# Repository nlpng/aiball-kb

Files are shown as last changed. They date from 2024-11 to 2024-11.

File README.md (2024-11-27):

# aiball keyboard
A 42-key splited keyboard inspired by [keyball](https://github.com/Yowkees/keyball) and [roBa](https://github.com/kumamuk-git/roBa), which has feature of trackball and wireless.

# Changes
The keyboard is based on roBa keyboard, and rework to fit my personal needs, since Corne keyboard layout is preferred, the key access feels better and more compact to me.

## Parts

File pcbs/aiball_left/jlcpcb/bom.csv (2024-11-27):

Designator | Footprint | Quantity | Value | LCSC Part #
B1 | JST_S2B-PH-SM4-TB | 1 | BATT
D1, D10, D11, D12, D13, D14, D15, D16, D17, D18, D19, D2, D20, D21, D22, D23, D3, D4, D5, D6, D7, D8, D9 | Diode_SMD | 23 | D
J1, J2, J3, J4, J5, J6, J7 | MountingHole_4.3mm_M4 | 7 | Conn_01x01-Connector_Generic
SW1, SW10, SW11, SW12, SW13, SW14, SW15, SW17, SW18, SW19, SW2, SW22, SW3, SW4, SW5, SW6, SW7, SW8, SW9 | SW_MX | 19 | SW_PUSH
SW16, SW20, SW23 | SW_MX_Choc | 3 | SW_PUSH
SW21 | SW_MX_EC12 | 1 | RotaryEncoder_Switch
SW24 | TGSW_MSK-12D19 | 1 | SW_SPDT
U1 | XIAO_nRF52840_wBAT_wNFC_1 | 1 | ~

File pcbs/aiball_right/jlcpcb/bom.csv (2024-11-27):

Designator | Footprint | Quantity | Value | LCSC Part #
BT1 | JST_S2B-PH-SM4-TB | 1 | BATT
D1, D10, D11, D12, D13, D14, D15, D16, D17, D18, D19, D2, D20, D3, D4, D5, D6, D7, D8, D9 | Diode_SMD | 20 | D
J1 | pmw3610_connector | 1 | ~
J2, J3, J4, J5, J6, J7 | MountingHole_4.3mm_M4 | 6 | Conn_01x01-Connector_Generic
SW1, SW10, SW11, SW13, SW14, SW15, SW17, SW18, SW19, SW2, SW20, SW3, SW4, SW5, SW6, SW7, SW8, SW9 | SW_MX | 18 | SW_PUSH
SW12, SW16 | SW_MX_Choc | 2 | SW_PUSH
SW21 | TGSW_MSK-12D19 | 1 | SW_SPDT
U1 | XIAO_nRF52840_wBAT_wNFC_1 | 1 | ~

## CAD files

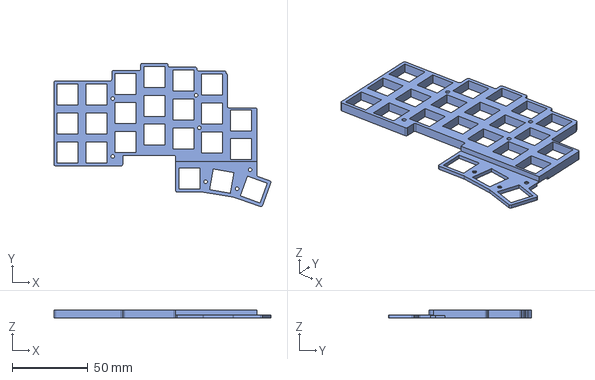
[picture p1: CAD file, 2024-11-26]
cases/step/left_top_plate.step
142.9 x 94.5 x 5.00 mm

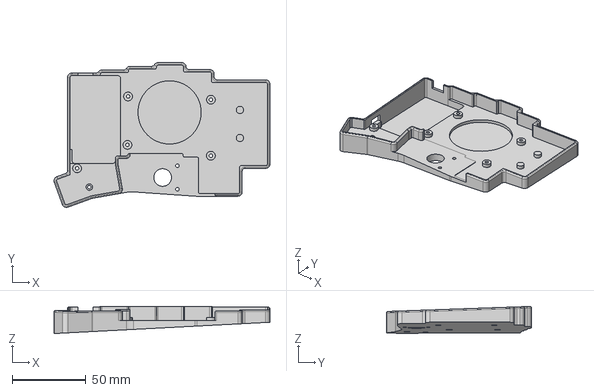
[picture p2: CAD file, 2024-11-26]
cases/step/right_bottom_plate.step
146.9 x 98.5 x 18.4 mm

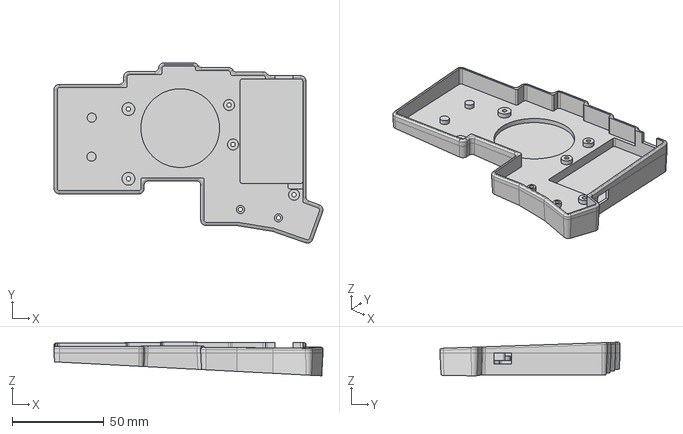
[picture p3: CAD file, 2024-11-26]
cases/step/left_bottom_plate.step
146.9 x 98.5 x 18.4 mm

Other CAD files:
cases/step/right_top_plate.step
cases/stl/left_bottom_plate.stl
cases/stl/left_top_plate.stl
cases/stl/right_top_plate.stl

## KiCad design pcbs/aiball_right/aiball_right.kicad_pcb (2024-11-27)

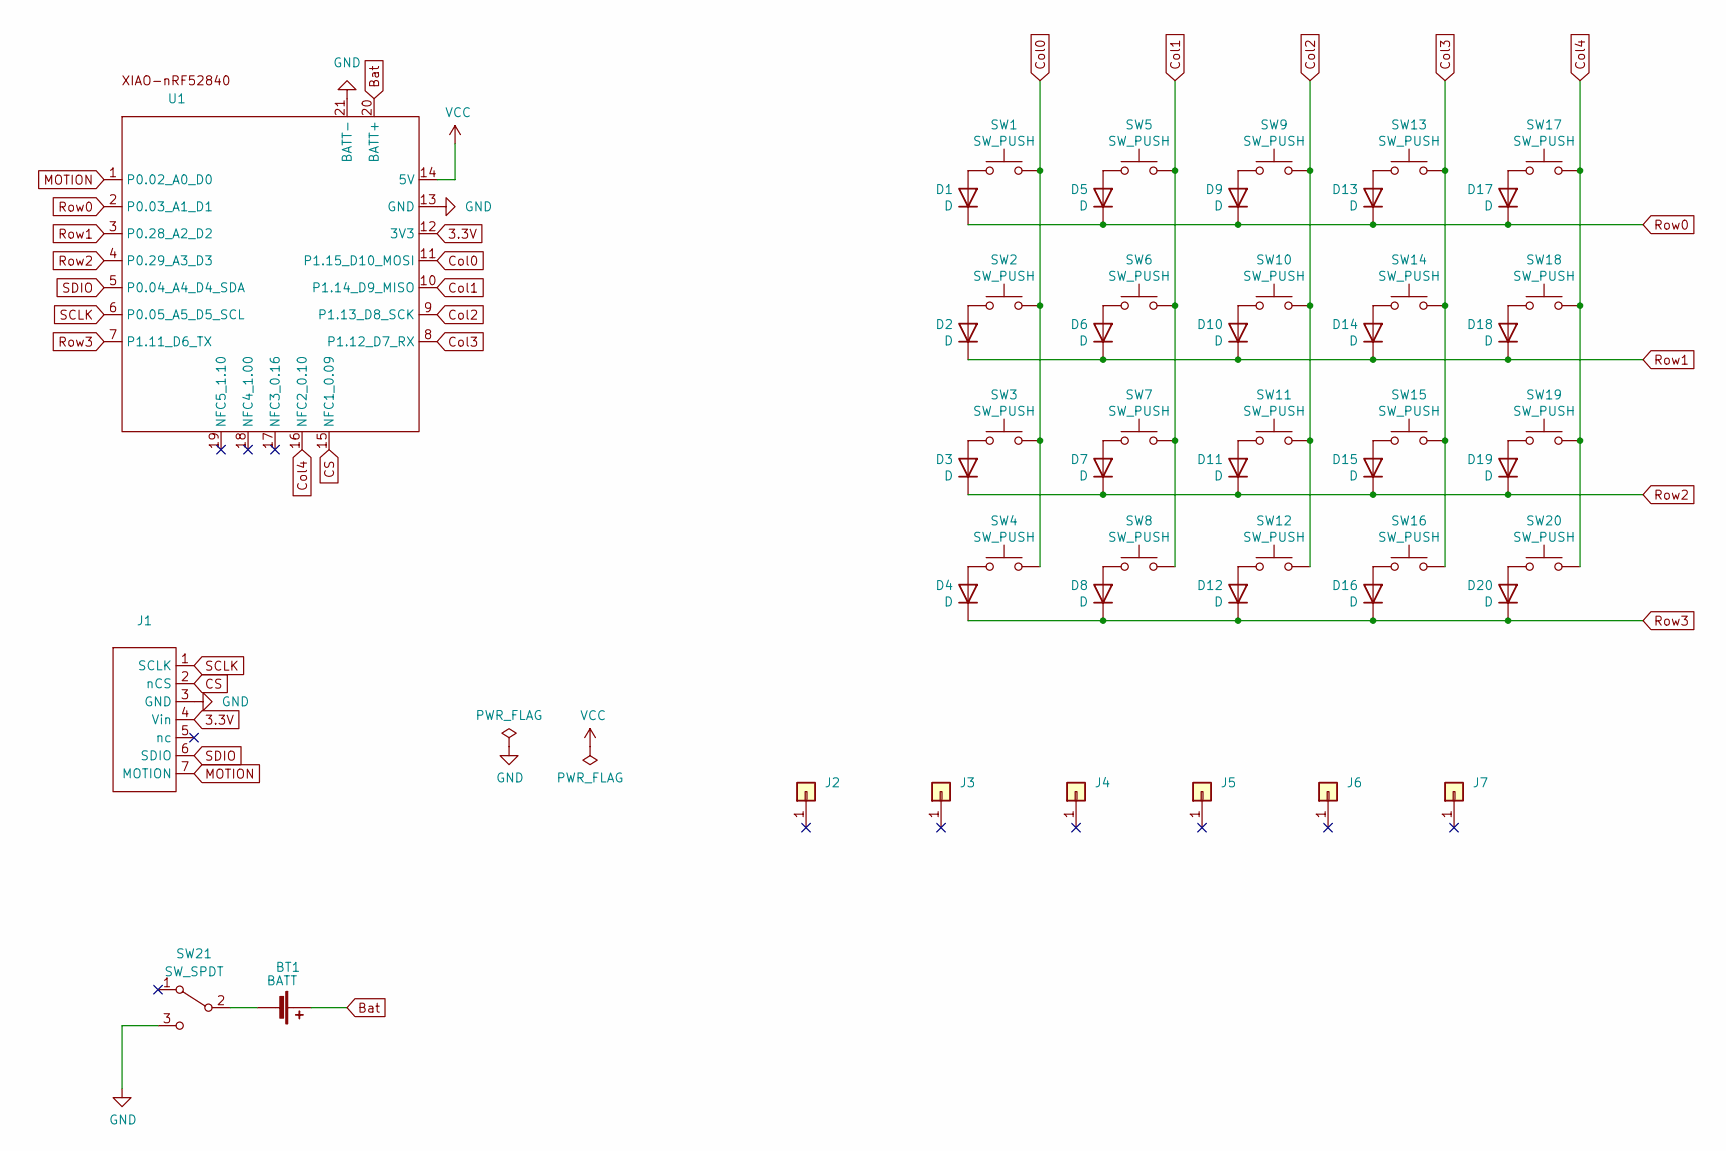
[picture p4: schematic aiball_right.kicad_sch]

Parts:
BT1: BATT; JST_S2B-PH-SM4-TB
D1, D2, D3, D4, D5, D6, D7, D8, D9, D10, D11, D12, D13, D14, D15, D16, D17, D18, D19, D20: D; Diode_SMD
J1: pmw3610_connector
J2, J3, J4, J5, J6, J7: Conn_01x01-Connector_Generic; MountingHole_4.3mm_M4
SW1, SW2, SW3, SW4, SW5, SW6, SW7, SW8, SW9, SW10, SW11, SW13, SW14, SW15, SW17, SW18, SW19, SW20: SW_PUSH; SW_MX
SW12, SW16: SW_PUSH; SW_MX_Choc
SW21: SW_SPDT; TGSW_MSK-12D19
U1: XIAO_nRF52840_wBAT_wNFC_1

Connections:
3.3V: J1.4 (Vin), U1.12 (3V3)
Bat: BT1.1 (+), U1.20 (BATT+)
CS: J1.2 (nCS), U1.15 (NFC1_0.09)
Col0: SW1.1, SW2.1, SW3.1, SW4.1, U1.11 (P1.15_D10_MOSI)
Col1: SW5.1, SW6.1, SW7.1, SW8.1, U1.10 (P1.14_D9_MISO)
Col2: SW9.1, SW10.1, SW11.1, SW12.1, U1.9 (P1.13_D8_SCK)
Col3: SW13.1, SW14.1, SW15.1, SW16.1, U1.8 (P1.12_D7_RX)
Col4: SW17.1, SW18.1, SW19.1, SW20.1, U1.16 (NFC2_0.10)
GND: J1.3 (GND), SW21.3 (C), U1.13 (GND), U1.21 (BATT-)
MOTION: J1.7 (MOTION), U1.1 (P0.02_A0_D0)
unnamed: BT1.2 (-), SW21.2 (B)
unnamed: D1.2 (A), SW1.2
unnamed: D2.2 (A), SW2.2
unnamed: D3.2 (A), SW3.2
unnamed: D4.2 (A), SW4.2
unnamed: D5.2 (A), SW5.2
unnamed: D6.2 (A), SW6.2
unnamed: D7.2 (A), SW7.2
unnamed: D8.2 (A), SW8.2
unnamed: D9.2 (A), SW9.2
unnamed: D10.2 (A), SW10.2
unnamed: D11.2 (A), SW11.2
unnamed: D12.2 (A), SW12.2
unnamed: D13.2 (A), SW13.2
unnamed: D14.2 (A), SW14.2
unnamed: D15.2 (A), SW15.2
unnamed: D16.2 (A), SW16.2
unnamed: D17.2 (A), SW17.2
unnamed: D18.2 (A), SW18.2
unnamed: D19.2 (A), SW19.2
unnamed: D20.2 (A), SW20.2
Row0: D1.1 (K), D5.1 (K), D9.1 (K), D13.1 (K), D17.1 (K), U1.2 (P0.03_A1_D1)
Row1: D2.1 (K), D6.1 (K), D10.1 (K), D14.1 (K), D18.1 (K), U1.3 (P0.28_A2_D2)
Row2: D3.1 (K), D7.1 (K), D11.1 (K), D15.1 (K), D19.1 (K), U1.4 (P0.29_A3_D3)
Row3: D4.1 (K), D8.1 (K), D12.1 (K), D16.1 (K), D20.1 (K), U1.7 (P1.11_D6_TX)
SCLK: J1.1 (SCLK), U1.6 (P0.05_A5_D5_SCL)
SDIO: J1.6 (SDIO), U1.5 (P0.04_A4_D4_SDA)
VCC: U1.14 (5V)

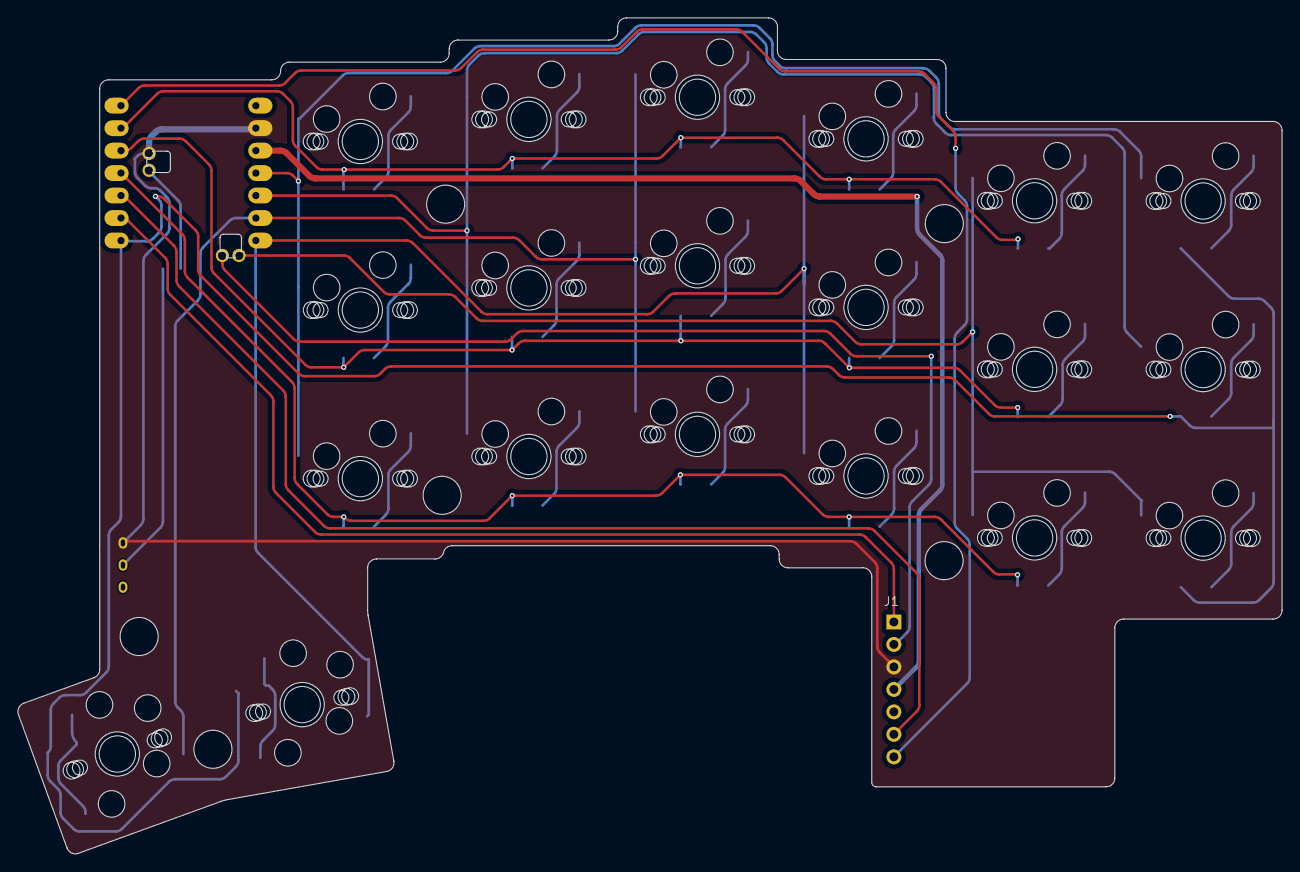
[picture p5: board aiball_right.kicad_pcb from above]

Board: 2 copper layers, 142.9 x 94.5 mm, 50 parts (1 on the bottom side), 37 nets.

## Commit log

2024-11-26 add cases
    [left_bottom_plate.step, left_bottom_plate.stl, left_top_plate.step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]
2024-11-27 add partial pcb files
    [aiball_left.kicad_pcb, aiball_left.kicad_sch, aiball_right.kicad_pcb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]
